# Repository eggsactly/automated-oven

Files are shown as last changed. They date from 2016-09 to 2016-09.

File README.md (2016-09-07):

# About
automated-oven contains models and code to implement a mount for a 1980s era Hotpoint electric range to control an oven with a smartphone. 

Two servo controlled oven knob placements over a Hotpoint oven (https://www.youtube.com/watch?v=Nlsh6EjL9IA)

# Building
To compile the code to machine readable form you will need to download and install the Arduino IDE
https://www.arduino.cc/en/Main/Software
You will also need to download and install OpenSCAD to render the 3D models:
http://www.openscad.org/downloads.html

You will need to order the parts listed in oven-project-parts.xml, 3D print the shapes in models and assemble the circuit below. 

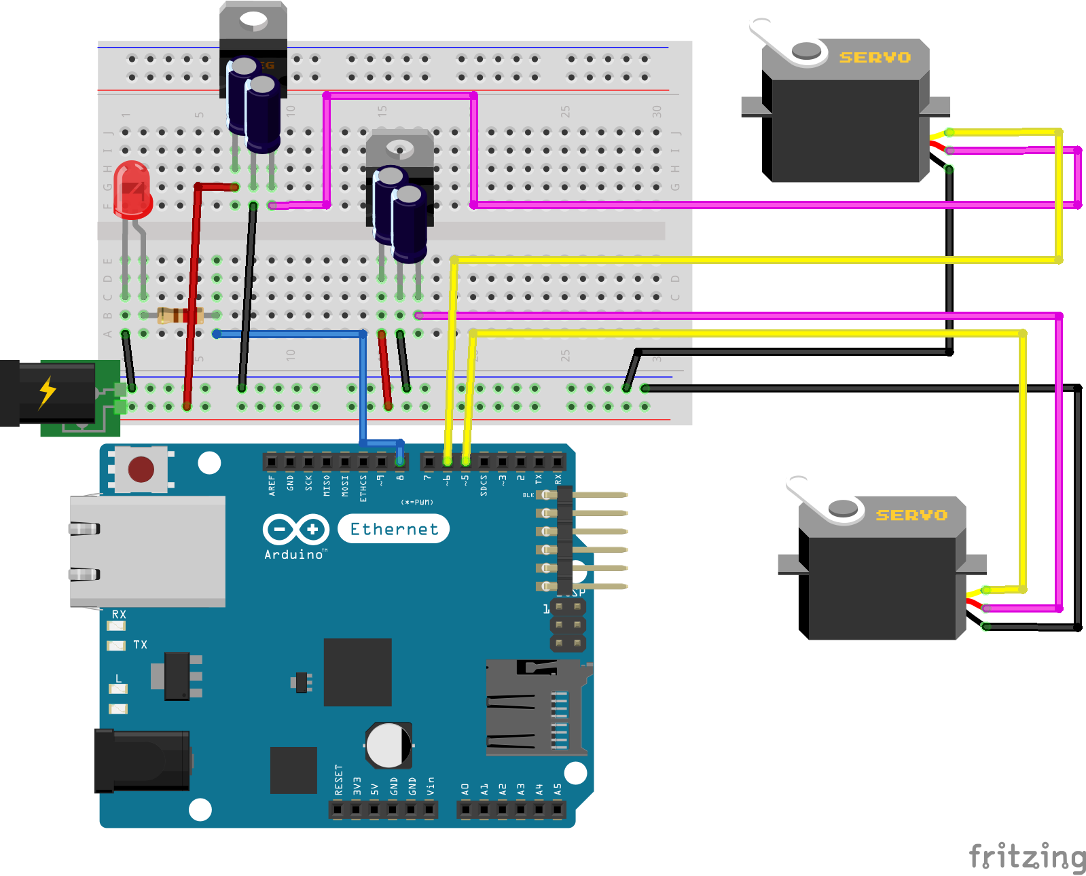
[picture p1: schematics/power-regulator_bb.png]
SVG circuit diagram of the servos hooked to the power regulators and the Arduino


Lastly, you will need to upload the contents of app/ and server-code/ to a PHP enabled web server and replace the byte array _server_ in firmware.ino with the IP address to your server. 

# License
automated-oven is free software: you can redistribute it and/or modify
it under the terms of the GNU General Public License as published by
the Free Software Foundation, either version 3 of the License, or
(at your option) any later version.

automated-oven is distributed in the hope that it will be useful,
but WITHOUT ANY WARRANTY; without even the implied warranty of
MERCHANTABILITY or FITNESS FOR A PARTICULAR PURPOSE.  See the
GNU General Public License for more details.

You should have received a copy of the GNU General Public License
along with automated-oven.  If not, see <http://www.gnu.org/licenses/>.

# Contents
- oven-project-parts.xml is a spreadsheet containing an itemized list of the parts needed to create the mount.
- app/ contains an AJAX webpage a smartphone shall run to control the oven.
- firmware/ contains code that runs on the Arduino Ethernet. 
- models/ contains OpenSCAD models of the physical oven mounts that are rendered to .stl files and 3D printed.
- schematics/ contains a diagram of the power supply circuitry and servos and how they connect to the Arduino.
- server-code/ contains code that runs on a server that coordinates communication between the smartphone and the Arduino.

# Areas for Improvement
- The servos were underpowered and unreliable towards their outer reach <45 degrees and >135 degrees, I would like to get better servos with better reliability and more power. 
- The voltage regulator circuit was liable to overheating. It overheated so much that in a 90 degree shift of the Off/Bake knob it could no longer provide the power to push the knob back to its original state. The regulator should be redesigned. 
- There should be a way for the Arduino to cut power to the servos and there should be a way to know which direction the servos are pointed in before delivering power. 
- Encryption needs to be added to the product

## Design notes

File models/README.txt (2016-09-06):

knob-fitting.scad, oven-fitting-bottom.scad and oven-fitting-top.scad are files that must be rendered with OpenSCAD and printed with a 3D printer. 
oven-fitting.scad is the two sides of oven-fitting-bottom.scad and oven-fitting-top.scad combined. The geometry of oven-fitting alone is more complex to print as one piece and requires high amounts of bridging, which is an ineffective use of extruding material. 
variables.scad contains a list of variables used by all .scad files, it has no renderable forms.

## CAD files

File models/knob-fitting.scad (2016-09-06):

/* Copyright (c) 2015 W.A. Garrett Weaver
 * This file is part of automated-oven
 *
 * automated-oven is free software: you can redistribute it and/or modify
 * it under the terms of the GNU General Public License as published by
 * the Free Software Foundation, either version 3 of the License, or
 * (at your option) any later version.
 *
 * automated-oven is distributed in the hope that it will be useful,
 * but WITHOUT ANY WARRANTY; without even the implied warranty of
 * MERCHANTABILITY or FITNESS FOR A PARTICULAR PURPOSE.  See the
 * GNU General Public License for more details.
 *
 * You should have received a copy of the GNU General Public License
 * along with automated-oven.  If not, see <http://www.gnu.org/licenses/>.
 */ 
include<variables.scad>

// Derived variables
knobRadius = knobDiameter/2; 
mountRadius = knobRadius + wallWidth;
mountHeight = knobHeight + wallWidth; 
nutWidthPrime = 1.1547 * nutWidth; 

m = (servoLeverWidthAt4thHole - servoLeverWidthAtFirstHole) / (3 * servoLeverHoleDist); 
b = servoLeverWidthAtFirstHole - (m * servoLeverFirstHoleDistFromCenter); 
yMax = (m * servoLeverLength) + b; 


difference() {
    //This is the main cylinder 
    cylinder(h = mountHeight, r1 = mountRadius, r2 = mountRadius, center = false, $fn = 360);
    
    // Everything below here is an extrusion on the main cylinder 
    
    // This cuts out the space for the knob
    translate(v = [0, 0, -diffOffset]) {
        cylinder(h = knobHeight + diffOffset, r1 = knobRadius, r2 = knobRadius, center = false, $fn = 360);
    }
    
    // This cuts out a place for the Bake, Off and Broil lables to show
    translate(v = [0, 0, knobHeight]) {
        difference() {
            translate(v = [0, 0, -diffOffset/2]) {
                cylinder(h = wallWidth + diffOffset, r1 = sightHoleOuterRad, r2 = sightHoleOuterRadTop, center = false, $fn = 360);
            }
            translate(v = [0, 0, -diffOffset]) {
                cylinder(h = wallWidth + 2 *diffOffset, r1 = sightHoleInnerRad, r2 = sightHoleInnerRad, center = false, $fn = 360);
            }
            rotate([0, 0, 45]) {
                translate(v = [-sightHoleOuterRadTop, -bridgeWidth/2, -3*diffOffset/2]) {
                    cube([2*sightHoleOuterRadTop, bridgeWidth, wallWidth + 3*diffOffset], center=false);
                }
                translate(v = [-bridgeWidth/2, -sightHoleOuterRadTop, -3*diffOffset/2]) {
                    cube([bridgeWidth, 2*sightHoleOuterRadTop , wallWidth + 3*diffOffset], center=false);
                }
            }
        }
    }
    
    // This cuts out a hole for the washer and the screw on the side
    translate(v = [0, 0, knobHeight/2]) {
        rotate([90, 0, 0]) {
            cylinder(h = knobRadius + wallWidth + diffOffset, r1 = screwRadius, r2 = screwRadius, center = false, $fn = 360);
            cylinder(h = nutHeight + knobRadius, r1 = nutWidthPrime/2, r2 = nutWidthPrime/2, center = false, $fn = 6);
        }
    }
    
    translate(v = [0, -knobRadius - 5, knobHeight/2]) {
        rotate([90, 0, 0]) {
            cylinder(h = knobRadius + wallWidth + diffOffset, r1 = screwHeadRadius, r2 = screwHeadRadius, center = false, $fn = 360);
        }
    }
    
    // This cuts out a hole for the servo lever
    translate(v = [0, 0, knobHeight + wallWidth - servoLeverHeight]) {
        union() {
            for(a=[0:3]){
                rotate([0, 0, 45 + (90 * a)]) {
                    polyhedron(
                        points = [[0, b, 0], [servoLeverLength, yMax, 0], [servoLeverLength, -yMax, 0], [0, -b, 0], [0, b, servoLeverHeight], [servoLeverLength, yMax, servoLeverHeight], [servoLeverLength, -yMax, servoLeverHeight], [0, -b, servoLeverHeight]], 
                        faces = [ [3, 1, 0], [2, 1, 3], [1, 4, 0], [1, 5, 4], [4, 5, 7], [6, 7, 5], [7, 6, 3], [6, 2, 3], [0, 4, 3], [4, 7, 3], [5, 1, 2], [5, 2, 6]]
                    );
                }
            }
        }
    }
    // This cuts out a place to fit a credit card under to disloge 
    for(a=[0:3]){
        rotate([0, 0, 45 + (90 * a)]) {
            translate(v = [knobRadius + wallWidth, 0, knobHeight + wallWidth]) {
                rotate([0, -90, 0]) {
                    cylinder(h = 5, r1 = 3, r2 = 0, center = false, $fn = 360);
                }
            }
        }
    }
    // This cuts out some margin for the servo lever center 
    translate(v = [0, 0, knobHeight + wallWidth - servoLeverHeight - 2]) {
        cylinder(h = servoLeverHeight + 2, r1 = servoLeverFirstHoleDistFromCenter, r2 = servoLeverFirstHoleDistFromCenter, center = false, $fn = 360);
    }
}

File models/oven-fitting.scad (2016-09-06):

/* Copyright (c) 2015 W.A. Garrett Weaver
 * This file is part of automated-oven
 *
 * automated-oven is free software: you can redistribute it and/or modify
 * it under the terms of the GNU General Public License as published by
 * the Free Software Foundation, either version 3 of the License, or
 * (at your option) any later version.
 *
 * automated-oven is distributed in the hope that it will be useful,
 * but WITHOUT ANY WARRANTY; without even the implied warranty of
 * MERCHANTABILITY or FITNESS FOR A PARTICULAR PURPOSE.  See the
 * GNU General Public License for more details.
 *
 * You should have received a copy of the GNU General Public License
 * along with automated-oven.  If not, see <http://www.gnu.org/licenses/>.
 */ 

include<variables.scad>
nutWidthPrime = 1.1547 * nutWidth; 
union() {
    difference() {
        union() {      
             // This is for the servo mount 
            translate(v = [bevelRadius - servoEdgeToCenter - ((servoMountWidth - servoLength)/2), bevelRadius - (servoWidth + wallThickness)/2, knobOffset + mountHeight]) {
                minkowski()
                {
                    cube([servoMountWidth + wallThickness - 2*bevelRadius, servoWidth + wallThickness - 2*bevelRadius, (servoHeight + wallThickness)/2], center=false);
                    cylinder(h = (servoHeight + wallThickness)/2, r1 = bevelRadius, r2 = bevelRadius, center = false, $fn = 360);
                }
            }
            // This if for the part which fits over the knob
            translate(v = [-plateWidth/2 + bevelRadius, -plateLength/2 + bevelRadius, 0]) {
                minkowski()
                {
                    cube([plateWidth - 2*bevelRadius, plateLength - 2*bevelRadius, (mountHeight + wallThickness + knobOffset)/2], center=false);
                    cylinder(h = (mountHeight + wallThickness + knobOffset)/2, r1 = bevelRadius, r2 = bevelRadius, center = false, $fn = 360);
                }
            }
            
        }
        // This cuts out the space for the knob
        cylinder(h = mountHeight + knobOffset, r1 = mountRadius + margin, r2 = mountRadius + margin, center = false, $fn = 360);
        
        // This cuts out a place for the servo
        translate(v = [-servoEdgeToCenter + wallThickness/2, -(servoWidth)/2, knobOffset + mountHeight]) {
            cube([servoLength, servoWidth, servoHeight], center=false);
        }
        
        //This cuts out a place for the servo below the part where we have the mounts 
        translate(v = [-servoEdgeToCenter + wallThickness/2 - ((servoMountWidth - servoLength)/2), -(servoWidth)/2, mountHeight]) {
            cube([servoMountWidth, servoWidth, servoMountDistToBody + knobOffset], center=false);
        }
        
        //This cuts off the top for the servo mount
        translate(v = [-servoEdgeToCenter - ((servoMountWidth - servoLength)/2), -(servoWidth + wallThickness)/2, knobOffset + mountHeight + servoHeight]) {
            cube([servoMountWidth + wallThickness, servoWidth + wallThickness, wallThickness], center=false);
        }
        
        // This cube cuts out a place for the servo wire mount to slide up on
        translate(v = [-servoEdgeToCenter, -servoWireMountWidth/2, knobOffset + mountHeight]) {
            cube([((servoMountWidth - servoLength)/2), servoWireMountWidth, knobOffset + mountHeight + wallThickness], center=false);
        }
        
        // This cuts out a space for the servo control wire to stick out 
        translate(v = [-servoEdgeToCenter - (servoMountWidth - servoLength)/2, -(servoWireMountWidth+3)/2, knobOffset + mountHeight + servoHeight - servoBottomToServoWire]) {
            cube([(servoMountWidth - servoLength), servoWireMountWidth + 3, servoBottomToServoWire], center=false);
        }
        
        // Cut out a space for the screws to use to mount the servo on 
        for(a=[0:1]) {
            for(b=[0:1]) {
                translate(v = [-servoEdgeToCenter + wallThickness/2 - ((servoMountWidth - servoLength)/4) + (a * (servoMountWidth - ((servoMountWidth - servoLength)/2))), (b * servoMountHoleDist) - (servoMountHoleDist/2), 0]) {
                    translate(v = [0, 0, bevelRadius + 0.70 * (knobOffset + mountHeight)/2]) {
                        cylinder(h =  knobOffset + mountHeight + 2 * wallThickness + servoHeight, r1 = screwRadius, r2 = screwRadius, center = false, $fn = 360);
                    }
                    translate(v = [0, 0, knobOffset + mountHeight + servoHeight - wallThickness - servoMountHexNutDistFromTop]) {
                        cylinder(h = servoMountHexNutDistFromTop + wallThickness, r1 = nutWidthPrime/2, r2 = nutWidthPrime/2, center = false, $fn = 6);
                    }
                }
            }
        }
        
        // Cut out holes for the sides 
        translate(v = [bevelRadius - (1 * knobDiameter)/2, -plateLength/2 - wallThickness, (bevelRadius + 0.70 * (knobOffset + mountHeight))/2]) {
            minkowski() {
                cube([1 * knobDiameter - 2*bevelRadius, plateLength/2 + wallThickness, 0.65 * (knobOffset + mountHeight) - 2*bevelRadius], center=false);
                rotate([-90, 0, 0]) {
                    cylinder(h = plateLength/2 + wallThickness, r1 = bevelRadius, r2 = bevelRadius, center = false, $fn = 360);
                }
            }
        }
        rotate([0, 0, 90]) {
            translate(v = [bevelRadius - (1 * knobDiameter)/2, -plateLength/2 - wallThickness, (bevelRadius + 0.70 * (knobOffset + mountHeight))/2]) {
                minkowski() {
                    cube([1 * knobDiameter - 2*bevelRadius, plateLength/2 + wallThickness, 0.65 * (knobOffset + mountHeight) - 2*bevelRadius], center=false);
                    rotate([-90, 0, 0]) {
                        cylinder(h = plateLength/2 + wallThickness, r1 = bevelRadius, r2 = bevelRadius, center = false, $fn = 360);
                    }
                }
            }
        }
        
        // Cut out holes for M2 screws
        for(a=[0:1]) {
            for(b=[0:1]) {
                translate(v = [(b * (plateWidth - 2*wallThickness)) - (plateWidth - 2*wallThickness)/2, (a * (plateLength - 2*wallThickness)) - (plateLength - 2*wallThickness)/2, 0]) {
                    translate(v = [0, 0, mountHeight + wallThickness - m2HeadHeight + knobOffset]) {
                        cylinder(h = m2HeadHeight, r1 = m2HeadDiameter/2, r2 = m2HeadDiameter/2, center = false, $fn = 360);
                    }
                    
                    cylinder(h = mountHeight + wallThickness + knobOffset, r1 = m2ThreadDiameter/2, r2 = m2ThreadDiameter/2, center = false, $fn = 360);
                    
                }
            }
        }
        rotate([0, 0, 180]) {
            // This cuts out a place for the Bake, Off and Broil lables to show when they're on 
            translate(v = [0, 0, mountHeight + knobOffset - 1]) {
                difference() { 

                    translate(v = [0, 0, 0]) {
                        cylinder(h = wallThickness + 1, r1 = sightHoleOuterRadTop, r2 = mountRadius, center = false, $fn = 360);
                    }
                        
                    
                    // This part is the 3/4ths of a pie to diff out the diff of the hole 
                    rotate([0, 0, 45]) {
                        cube([plateLength, plateLength, servoHeight + wallThickness + mountHeight + knobOffset], center=false);
                        translate(v = [0, -plateLength, 0]) {
                            cube([plateLength, plateLength, servoHeight + wallThickness + mountHeight + knobOffset], center=false);
                        }
                        translate(v = [-plateLength, 0, 0]) {
                            cube([plateLength, plateLength, servoHeight + wallThickness + mountHeight + knobOffset], center=false);
                        }
                    }
                }
            }
        }
    }

    translate(v = [0, 0, mountHeight + knobOffset]) {
        translate(v = [-plateLength/2, servoWidth/2 , 0]) {
            cube([plateLength, wallThickness/2, wallThickness], center=false);
        }
    }
}

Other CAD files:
models/oven-fitting-bottom.scad
models/oven-fitting-top.scad
models/variables.scad

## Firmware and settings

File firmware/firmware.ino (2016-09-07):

/* Copyright (c) 2015 W.A. Garrett Weaver
 * This file is part of automated-oven
 *
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
 * You should have received a copy of the GNU General Public License
 * along with automated-oven.  If not, see <http://www.gnu.org/licenses/>.
 */ 
#include <Ethernet.h>
#include <SPI.h>
#include <Servo.h> 

#define LEFT_SERVO 5
#define RIGHT_SERVO 6
#define CONNECT_LED 9
#define BAKE_LED 8

#define OFF_ANGLE 45
#define BAKE_ANGLE 135

////////////////////////////////////////////////////////////////////////
//CONFIGURE
////////////////////////////////////////////////////////////////////////
byte server[] = {192, 168, 1, 100}; //ip Address of the server you will connect to

//The location to go to on the server
//make sure to keep HTTP/1.0 at the end, this is telling it what type of file it is
String location = "/oven-get.php HTTP/1.0";


// if need to change the MAC address (Very Rare)
byte mac[] = { 0x90, 0xA2, 0xDA, 0x10, 0x2A, 0xEF };
////////////////////////////////////////////////////////////////////////

EthernetClient client;

Servo bakeServo;
Servo tempServo; 
unsigned servoAngle; 

char inString[32]; // string for incoming serial data
int stringPos = 0; // string index counter
boolean startRead = false; // is reading?

void setup(){
  Ethernet.begin(mac);
  Serial.begin(9600);
  
  bakeServo.attach(LEFT_SERVO);
  tempServo.attach(RIGHT_SERVO); 
  
  pinMode(CONNECT_LED, OUTPUT);
  pinMode(BAKE_LED, OUTPUT);
  
  
  digitalWrite(CONNECT_LED, LOW);
  digitalWrite(BAKE_LED, LOW);
}

void loop() {
  String pageValue = connectAndRead(); //connect to the server and read the output
  
  // Decode the values

  Serial.print("Bake Value: ");
  Serial.println(pageValue.charAt(0));
  
  Serial.print("Temp Value: ");
  Serial.println(pageValue.substring(2).toInt());

  // If we have enough info
  if(pageValue.length() > 2) {
    
    // Control the left servo 
    if(pageValue.charAt(0) == '2') {
      bakeServo.write(BAKE_ANGLE);
      digitalWrite(BAKE_LED, HIGH);
    }
    else {
      bakeServo.write(OFF_ANGLE);
      digitalWrite(BAKE_LED, LOW);
    }
    
    // Control the right serco
    tempServo.write(pageValue.substring(2).toInt());
  }

  delay(5000); //wait 5 seconds before connecting again
}



String connectAndRead(){
  //connect to the server

  Serial.println("connecting...");

  //port 80 is typical of a www page
  if (client.connect(server, 80)) {
    digitalWrite(CONNECT_LED, HIGH);
    
    Serial.println("connected");
    client.print("GET ");
    client.println(location);
    client.println();

    //Connected - Read the page
    return readPage(); //go and read the output

  }else{
    digitalWrite(CONNECT_LED, LOW);
    return "connection failed";
  }

}

String readPage(){
  //read the page, and capture & return everything between '<' and '>'

  stringPos = 0;
  memset( &inString, 0, 32 ); //clear inString memory

  while(true){

    if (client.available()) {
      char c = client.read();

      if (c == '<' ) { //'<' is our begining character
        startRead = true; //Ready to start reading the part 
      }else if(startRead){

        if(c != '>'){ //'>' is our ending character
          inString[stringPos] = c;
          stringPos ++;
        }else{
          //got what we need here! We can disconnect now
          startRead = false;
          client.stop();
          client.flush();
          Serial.println("disconnecting.");
          return inString;
        }
      }
    }
  }
}

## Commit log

2015-10-31 Created knob-fitting.scad file, which is a 3D model for the mount that will go around the oven knob.
    [knob-fitting.scad]
2015-10-31 Added variables to knob-fitting design.
    [knob-fitting.scad]
2015-10-31 Added holes in knob-fitting to allow user to see bake, off and broil settings.
    [knob-fitting.scad]
2015-11-02 Added place for circular servo fitting.
    [knob-fitting.scad]
2015-11-02 Made screw hole use nut without washer.
    [knob-fitting.scad]
2015-11-03 Added cut out for 4 sided servo lever and expanded cut out for screw.
    [knob-fitting.scad]
2015-11-04 Made holes for Bake, Off and Broil larger and made them slanted on the outside.
    [knob-fitting.scad]
2015-11-04 Expanded hex nut hole width.
    [knob-fitting.scad]
2015-11-04 Made lever socket calculated through variables and repeated with a for loop.
    [knob-fitting.scad]
2015-11-04 Increased size of servo lever slot based on new measurements.
    [knob-fitting.scad]
2015-11-04 Added cone cut outs to knob fitting to make it easier to remove from print surface.
    [knob-fitting.scad]
2015-11-08 Added file for oven fitting.
    [oven-fitting.scad]
2015-11-08 Expanded fitting and created hole for knob to fit in.
    [oven-fitting.scad]
2015-11-08 Added offset on oven fitting to account for space between oven space and knob.
    [oven-fitting.scad]
2015-11-08 Added Minkowski transform to round corners on oven mount.
    [oven-fitting.scad]
2015-11-09 Created place for servo to go on the oven fitting.
    [oven-fitting.scad]
2015-11-10 Added variables.scad file, so all scad designs can reference the same values.
    [knob-fitting.scad, oven-fitting.scad, variables.scad]
2015-11-10 Created hole on top of oven-fitting for servo to poke through.
    [oven-fitting.scad]
2015-11-10 Added cut out for wire to stick out on the oven fitting.
    [oven-fitting.scad, variables.scad]
2015-11-10 Added screw holes for the servo.
    [oven-fitting.scad, variables.scad]
2015-11-10 Added bevel around servo mounting.
    [oven-fitting.scad]
2015-11-10 Corrected size of oven mounting.
    [oven-fitting.scad, variables.scad]
2015-11-10 Cut out holes on the side of the oven fitting.
    [oven-fitting.scad]
2015-11-10 Created top and bottom sections to the oven fittings, added screw holes to hold them together.
    [oven-fitting-bottom.scad, oven-fitting-top.scad, oven-fitting.scad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]
2015-11-11 Added hole on the oven mount so use can see what setting the oven is on.
    [knob-fitting.scad, oven-fitting.scad]
2015-11-12 Updated values and model for oven fitting after first print showed some things were too wide, others too narrow.
    [oven-fitting.scad, variables.scad]
2015-11-13 Changed knob offset variable to 8, 12 is a bit too high.
    [variables.scad]
2015-11-13 Changed model to attach oven fitting top and bottom with m3 screws instead of m2.
    [variables.scad]
2015-11-20 Put M3 screw head holes in right possition, Rotated oven mount, added file for server.
    [oven-fitting.scad, variables.scad]
2015-11-24 Added more code for the Arduino.
2015-11-29 Organized files and added README files.
    [knob-fitting.scad, oven-fitting-bottom.scad, oven-fitting-top.scad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]
2015-11-29 Added Copyright statement.
    [knob-fitting.scad, oven-fitting-bottom.scad, oven-fitting-top.scad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]
2015-11-29 Added circuit diagram.
2015-11-29 Updated README to explain schematics directory.
2015-11-29 Added debugging feature, LED L9 will turn on when the Arduino is connected to the server.
2015-11-29 Updated power regulator circuit to include LED I added to indicate that oven should be on.
2016-09-06 Added GPL license everywhere.
    [knob-fitting.scad, oven-fitting-bottom.scad, oven-fitting-top.scad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]
2016-09-06 Made the circuit diagram a png.
